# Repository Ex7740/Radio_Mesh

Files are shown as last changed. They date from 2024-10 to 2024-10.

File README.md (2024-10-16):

# Radio Mesh

A custom mesh network utilising 2.4GHz radio nodes using microcontrollers and nrf24l01

There are 3 types of node:

# Basic node: 
Simply just the microcontroller and nrf24l01 modules 

# Sensor node: 
More complex, Houses the microcontroller and nrf24l01, plus a varity of sensors, dependant on the application

# Storage node: 
Houses a Flash chip to hold sensor data and other data

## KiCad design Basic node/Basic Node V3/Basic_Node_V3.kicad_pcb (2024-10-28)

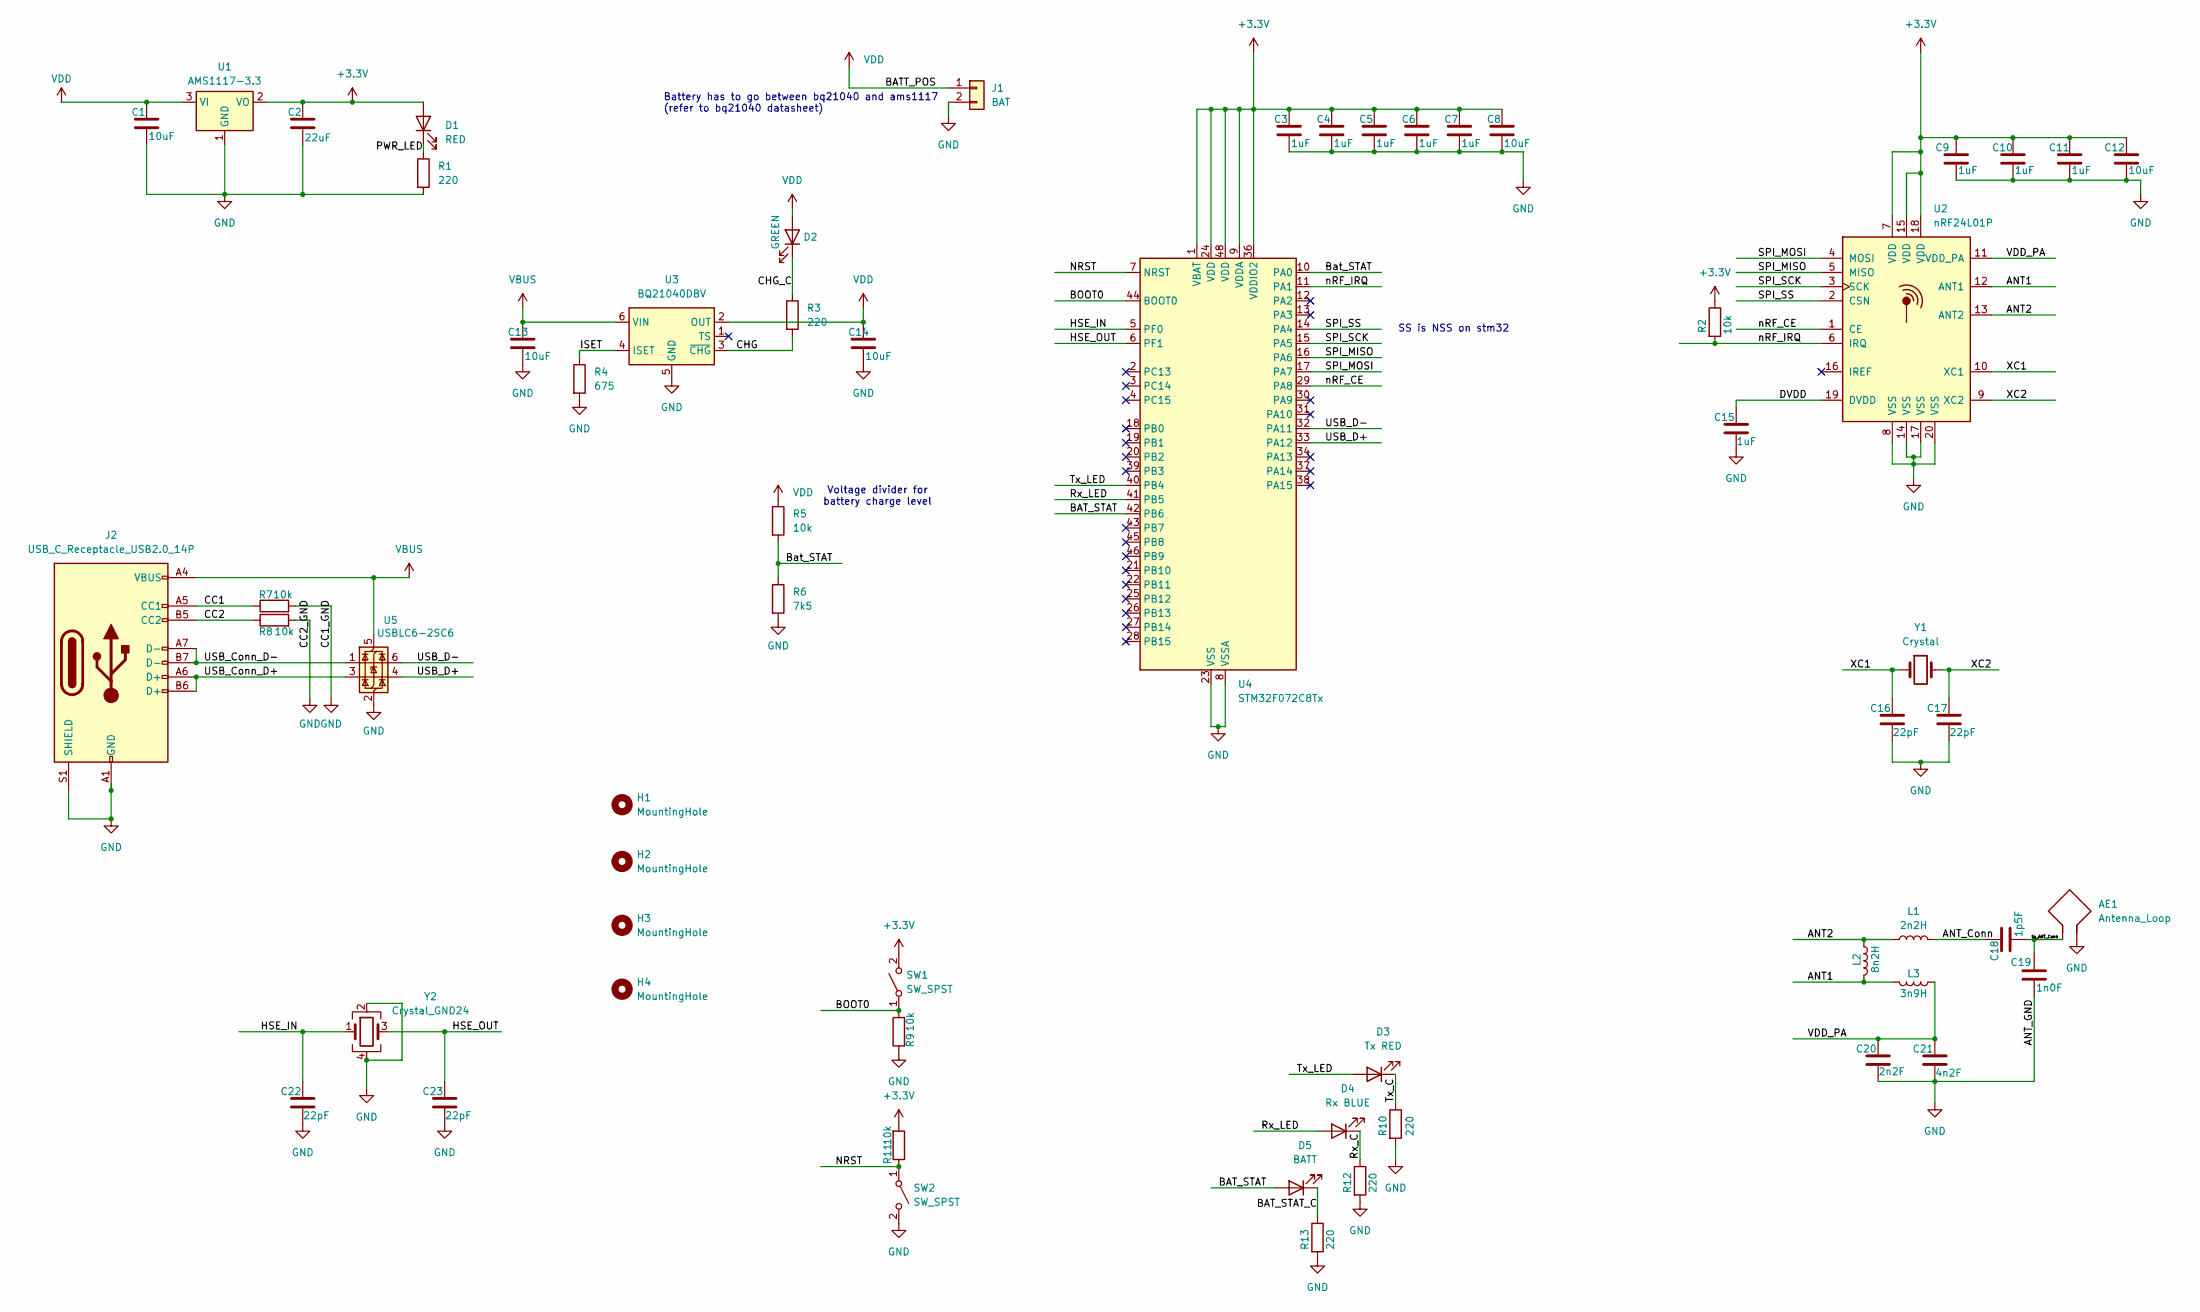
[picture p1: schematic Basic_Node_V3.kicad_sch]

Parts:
AE1: Antenna_Loop; Texas_SWRA117D_2.4GHz_Left
C1, C14: 10uF; C_0402_1005Metric
C2: 22uF; C_0402_1005Metric
C3, C4, C5, C6, C7, C9, C10, C11, C15: 1uF; C_0402_1005Metric
C8, C12, C13: 10uF; C_0603_1608Metric
C16, C17, C22, C23: 22pF; C_0402_1005Metric
C18: 1p5F; C_0402_1005Metric
C19: 1n0F; C_0402_1005Metric
C20: 2n2F; C_0402_1005Metric
C21: 4n2F; C_0402_1005Metric
D1: RED; LED_0603_1608Metric
D2: GREEN; LED_0603_1608Metric
D3: Tx RED; LED_0805_2012Metric
D4: Rx BLUE; LED_0805_2012Metric
D5: BATT; LED_0805_2012Metric
H1, H2, H3, H4: MountingHole; MountingHole_2.2mm_M2
J1: BAT; JST_PH_S2B-PH-K_1x02_P2.00mm_Horizontal
J2: USB_C_Receptacle_USB2.0_14P; USB_C_Receptacle_HRO_TYPE-C-31-M-12
L1: 2n2H; L_0603_1608Metric
L2: 8n2H; L_0603_1608Metric
L3: 3n9H; L_0603_1608Metric
R1, R3, R10, R12, R13: 220; R_0603_1608Metric
R2, R5, R8, R9, R11: 10k; R_0603_1608Metric
R4: 675; R_0603_1608Metric
R6: 7k5; R_0603_1608Metric
R7: 10k; L_0603_1608Metric
SW1, SW2: SW_SPST; SW_PUSH_6mm
U1: AMS1117-3.3; SOT-223-3_TabPin2
U2: nRF24L01P; QFN-20-1EP_4x4mm_P0.5mm_EP2.5x2.5mm
U3: BQ21040DBV; SOT-23-6
U4: STM32F072C8Tx; LQFP-48_7x7mm_P0.5mm
U5: USBLC6-2SC6; SOT-23-6
Y1: Crystal; Crystal_SMD_0603-2Pin_6.0x3.5mm
Y2: Crystal_GND24; Crystal_SMD_0603-4Pin_6.0x3.5mm

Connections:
+3.3V: C2.1, C3.1, C4.1, C5.1, C6.1, C7.1, C8.1, C9.1, C10.1, C11.1, C12.1, D1.2 (A), R2.1, R11.2, SW1.2 (B), U1.2 (VO), U2.7 (VDD), U2.15 (VDD), U2.18 (VDD), U4.1 (VBAT), U4.9 (VDDA), U4.24 (VDD), U4.36 (VDDIO2), U4.48 (VDD)
/ANT1: L2.2, L3.2, U2.12 (ANT1)
/ANT2: L1.1, L2.1, U2.13 (ANT2)
/ANT_Conn: C18.1, L1.2
/BAT_STAT: D5.2 (A), U4.42 (PB6)
/BAT_STAT_C: D5.1 (K), R13.1
/BOOT0: R9.2, SW1.1 (A), U4.44 (BOOT0)
/Bat_STAT: R5.2, R6.1, U4.10 (PA0)
/CC1: J2.A5 (CC1), R7.1
/CC2: J2.B5 (CC2), R8.1
/CHG: R3.2, U3.3 (~CHG)
/CHG_C: D2.1 (K), R3.1
/DVDD: C15.1, U2.19 (DVDD)
/HSE_IN: C22.1, U4.5 (PF0), Y2.1
/HSE_OUT: C23.1, U4.6 (PF1), Y2.3
/ISET: R4.1, U3.4 (ISET)
/NRST: R11.1, SW2.1 (A), U4.7 (NRST)
/PWR_LED: D1.1 (K), R1.1
/Rx_C: D4.1 (K), R12.1
/Rx_LED: D4.2 (A), U4.41 (PB5)
/SPI_MISO: U2.5 (MISO), U4.16 (PA6)
/SPI_MOSI: U2.4 (MOSI), U4.17 (PA7)
/SPI_SCK: U2.3 (SCK), U4.15 (PA5)
/SPI_SS: U2.2 (CSN), U4.14 (PA4)
/Tx_C: D3.1 (K), R10.1
/Tx_LED: D3.2 (A), U4.40 (PB4)
/USB_Conn_D+: J2.A6 (D+), J2.B6 (D+), U5.3 (I/O2)
/USB_Conn_D-: J2.A7 (D-), J2.B7 (D-), U5.1 (I/O1)
/USB_D+: U4.33 (PA12), U5.4 (I/O2)
/USB_D-: U4.32 (PA11), U5.6 (I/O1)
/VDD_PA: C20.1, C21.1, L3.1, U2.11 (VDD_PA)
/XC1: C16.1, U2.10 (XC1), Y1.1
/XC2: C17.1, U2.9 (XC2), Y1.2
/nRF_CE: U2.1 (CE), U4.29 (PA8)
/nRF_IRQ: R2.2, U2.6 (IRQ), U4.11 (PA1)
/to_ANT_Conn: AE1.1, C18.2, C19.1
GND: AE1.2, C1.2, C2.2, C3.2, C4.2, C5.2, C6.2, C7.2, C8.2, C9.2, C10.2, C11.2, C12.2, C13.2, C14.2, C15.2, C16.2, C17.2, C19.2, C20.2, C21.2, C22.2, C23.2, J1.2, J2.A1 (GND), J2.A12 (GND), J2.B1 (GND), J2.B12 (GND), J2.S1 (SHIELD), R1.2, R4.2, R6.2, R7.2, R8.2, R9.1, R10.2, R12.2, R13.2, SW2.2 (B), U1.1 (GND), U2.8 (VSS), U2.14 (VSS), U2.17 (VSS), U2.20 (VSS), U3.5 (GND), U4.8 (VSSA), U4.23 (VSS), U4.35 (VSS), U4.47 (VSS), U5.2 (GND), Y2.2, Y2.4
VBUS: C13.1, J2.A4 (VBUS), J2.A9 (VBUS), J2.B4 (VBUS), J2.B9 (VBUS), U3.6 (VIN), U5.5 (VBUS)
VDD: C1.1, C14.1, D2.2 (A), J1.1, R5.1, U1.3 (VI), U3.2 (OUT)

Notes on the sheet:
Voltage divider for battery charge level
Battery has to go between bq21040 and ams1117 (refer to bq21040 datasheet)
SS is NSS on stm32

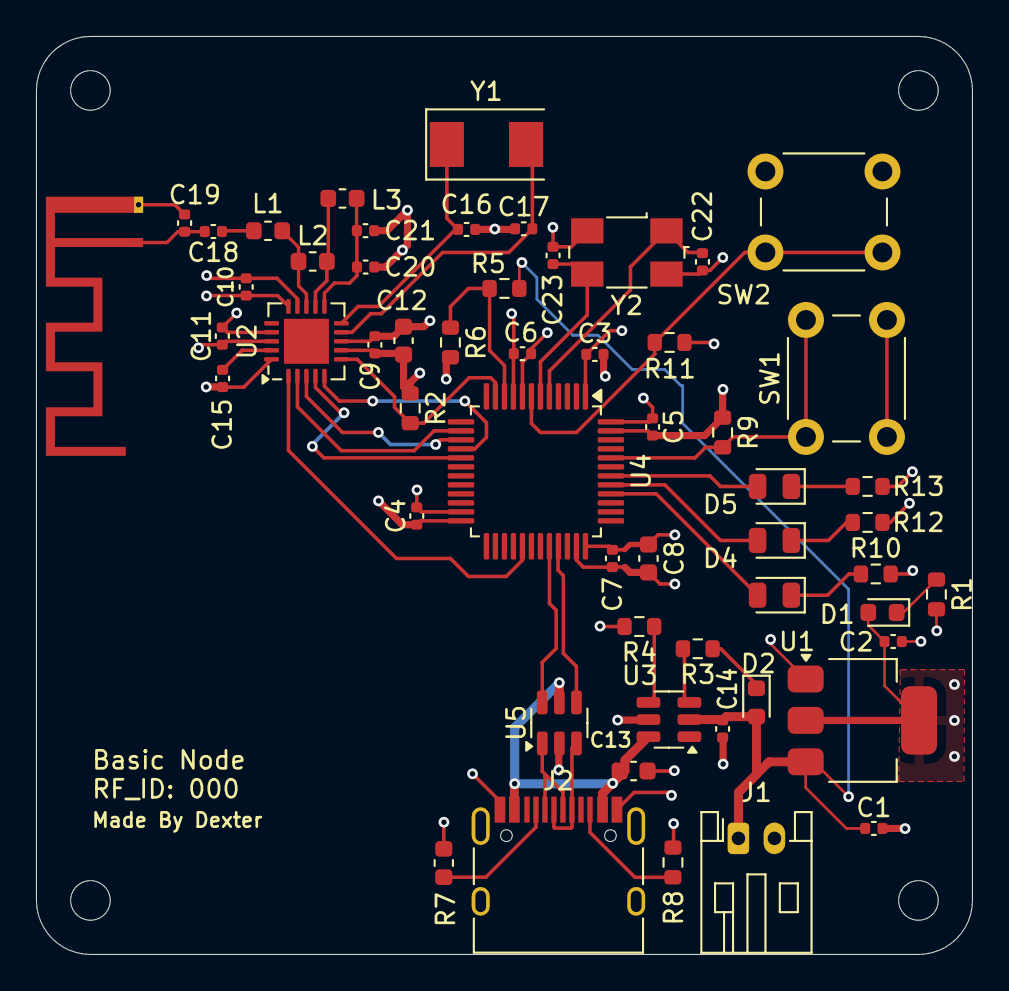
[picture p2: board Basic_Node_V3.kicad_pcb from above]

Board: 4 copper layers, 52.0 x 51.0 mm, 60 parts (0 on the bottom side), 39 nets.

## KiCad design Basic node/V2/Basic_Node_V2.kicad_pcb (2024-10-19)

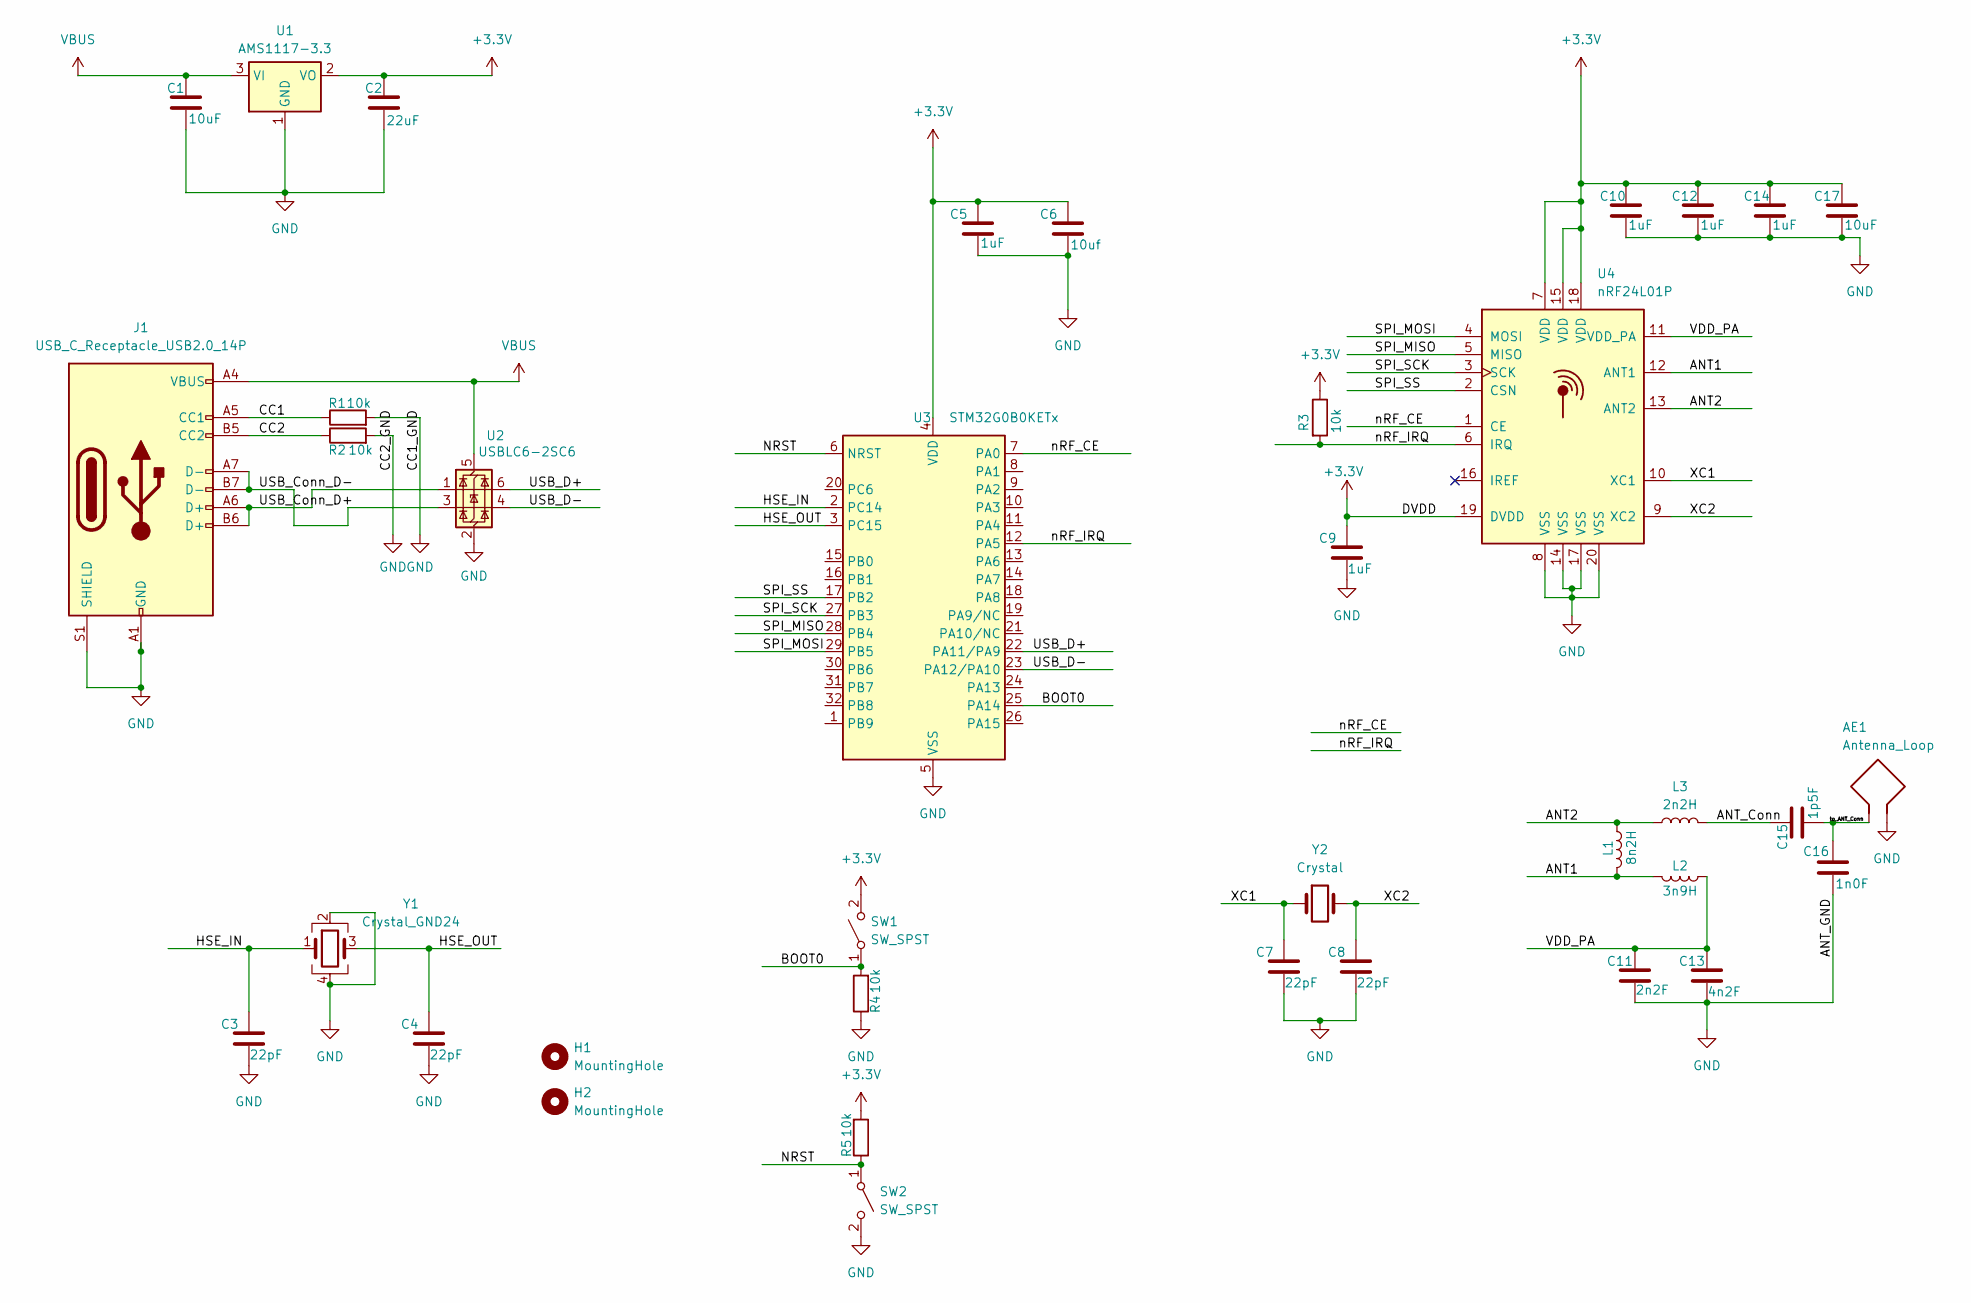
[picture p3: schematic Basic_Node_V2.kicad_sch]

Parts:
AE1: Antenna_Loop; Texas_SWRA117D_2.4GHz_Left
C1: 10uF; C_0402_1005Metric
C2: 22uF; C_0402_1005Metric
C3, C4, C7, C8: 22pF; C_0402_1005Metric
C5, C9, C10, C12, C14: 1uF; C_0402_1005Metric
C6: 10uf; C_0603_1608Metric
C11: 2n2F; C_0402_1005Metric
C13: 4n2F; C_0402_1005Metric
C15: 1p5F; C_0402_1005Metric
C16: 1n0F; C_0402_1005Metric
C17: 10uF; C_0603_1608Metric
H1, H2: MountingHole; MountingHole_2.2mm_M2
J1: USB_C_Receptacle_USB2.0_14P; USB_C_Receptacle_HRO_TYPE-C-31-M-12
L1: 8n2H; L_0603_1608Metric
L2: 3n9H; L_0603_1608Metric
L3: 2n2H; L_0603_1608Metric
R1: 10k; L_0603_1608Metric
R2, R3, R4, R5: 10k; R_0603_1608Metric
SW1, SW2: SW_SPST; SW_PUSH_6mm
U1: AMS1117-3.3; SOT-223-3_TabPin2
U2: USBLC6-2SC6; SOT-23-6
U3: STM32G0B0KETx; LQFP-32_7x7mm_P0.8mm
U4: nRF24L01P; QFN-20-1EP_4x4mm_P0.5mm_EP2.5x2.5mm
Y1: Crystal_GND24; Crystal_SMD_0603-4Pin_6.0x3.5mm
Y2: Crystal; Crystal_SMD_0603-2Pin_6.0x3.5mm

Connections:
+3.3V: C2.1, C5.1, C6.1, C9.1, C10.1, C12.1, C14.1, C17.1, R3.1, R5.2, SW1.2 (B), U1.2 (VO), U3.4 (VDD), U4.7 (VDD), U4.15 (VDD), U4.18 (VDD), U4.19 (DVDD)
/ANT1: L1.2, L2.2, U4.12 (ANT1)
/ANT2: L1.1, L3.1, U4.13 (ANT2)
/ANT_Conn: C15.1, L3.2
/BOOT0: R4.2, SW1.1 (A), U3.25 (PA14)
/CC1: J1.A5 (CC1), R1.1
/CC2: J1.B5 (CC2), R2.1
/HSE_IN: C3.1, U3.2 (PC14), Y1.1
/HSE_OUT: C4.1, U3.3 (PC15), Y1.3
/NRST: R5.1, SW2.1 (A), U3.6 (NRST)
/SPI_MISO: U3.28 (PB4), U4.5 (MISO)
/SPI_MOSI: U3.29 (PB5), U4.4 (MOSI)
/SPI_SCK: U3.27 (PB3), U4.3 (SCK)
/SPI_SS: U3.17 (PB2), U4.2 (CSN)
/USB_Conn_D+: J1.A6 (D+), J1.B6 (D+), U2.1 (I/O1)
/USB_Conn_D-: J1.A7 (D-), J1.B7 (D-), U2.3 (I/O2)
/USB_D+: U2.6 (I/O1), U3.22 (PA11/PA9)
/USB_D-: U2.4 (I/O2), U3.23 (PA12/PA10)
/VDD_PA: C11.1, C13.1, L2.1, U4.11 (VDD_PA)
/XC1: C7.1, U4.10 (XC1), Y2.1
/XC2: C8.1, U4.9 (XC2), Y2.2
/nRF_CE: U3.7 (PA0), U4.1 (CE)
/nRF_IRQ: R3.2, U3.12 (PA5), U4.6 (IRQ)
/to_ANT_Conn: AE1.1, C15.2, C16.1
GND: AE1.2, C1.2, C2.2, C3.2, C4.2, C5.2, C6.2, C7.2, C8.2, C9.2, C10.2, C11.2, C12.2, C13.2, C14.2, C16.2, C17.2, J1.A1 (GND), J1.A12 (GND), J1.B1 (GND), J1.B12 (GND), J1.S1 (SHIELD), R1.2, R2.2, R4.1, SW2.2 (B), U1.1 (GND), U2.2 (GND), U3.5 (VSS), U4.8 (VSS), U4.14 (VSS), U4.17 (VSS), U4.20 (VSS), Y1.2, Y1.4
VBUS: C1.1, J1.A4 (VBUS), J1.A9 (VBUS), J1.B4 (VBUS), J1.B9 (VBUS), U1.3 (VI), U2.5 (VBUS)

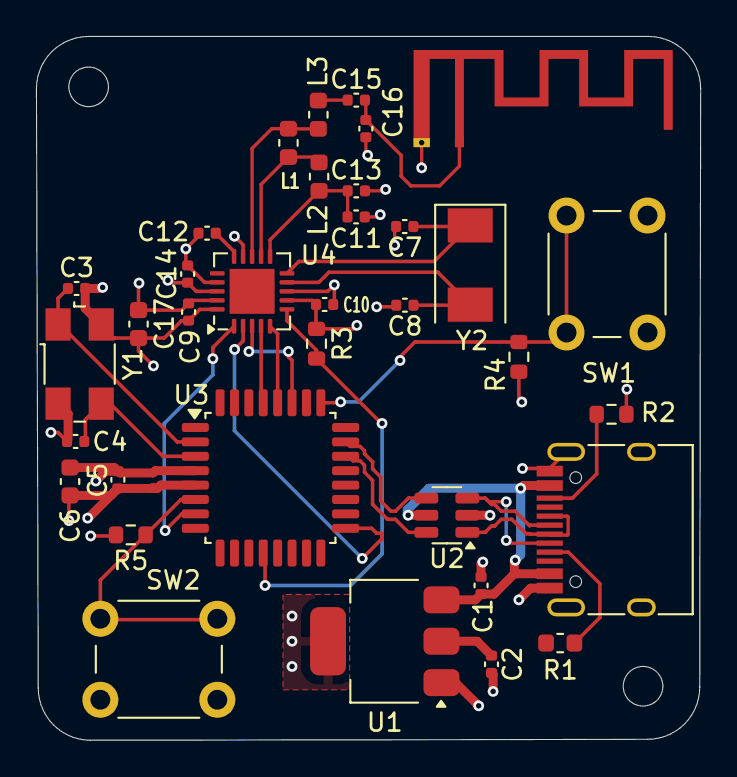
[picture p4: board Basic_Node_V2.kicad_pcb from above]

Board: 4 copper layers, 36.9 x 39.1 mm, 37 parts (0 on the bottom side), 26 nets.

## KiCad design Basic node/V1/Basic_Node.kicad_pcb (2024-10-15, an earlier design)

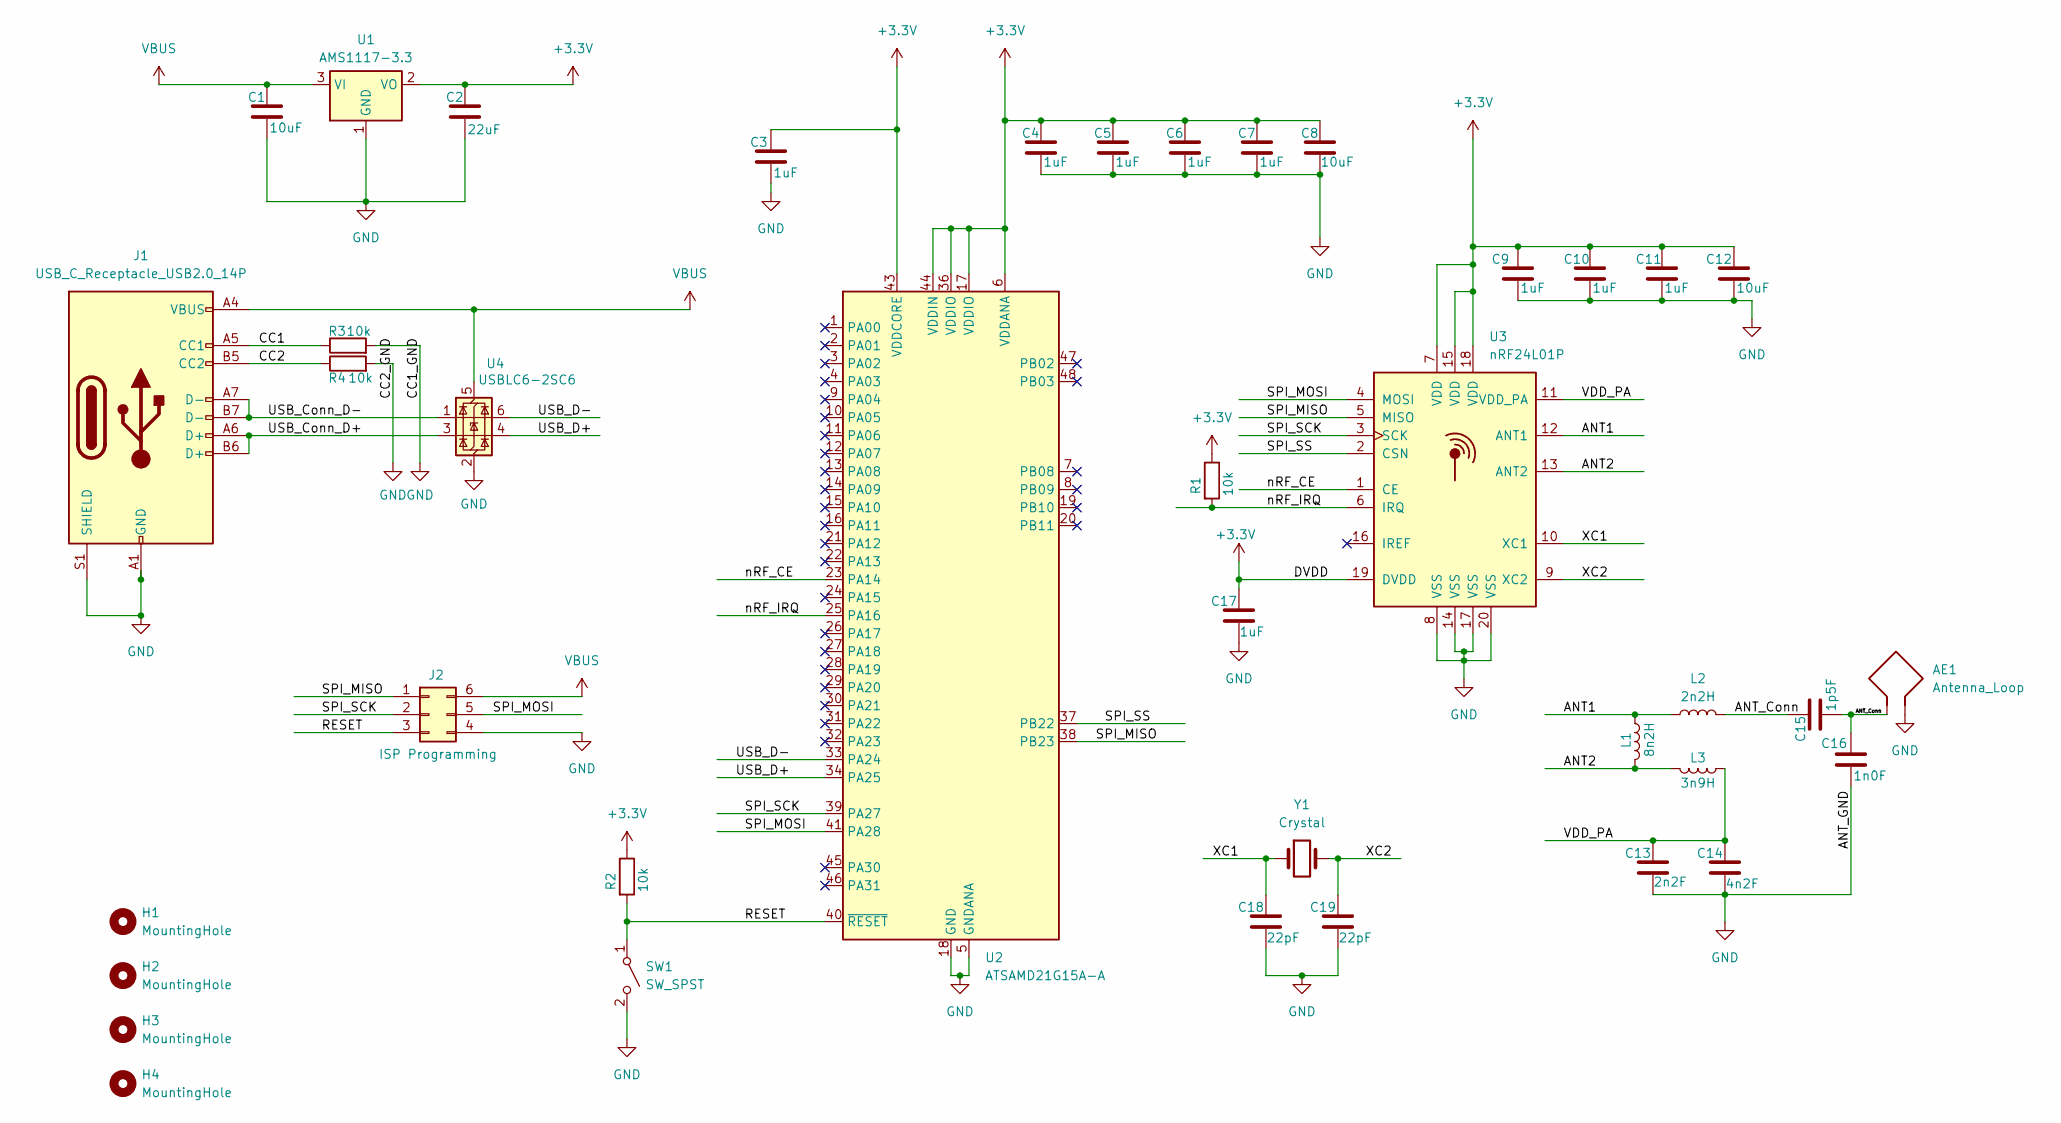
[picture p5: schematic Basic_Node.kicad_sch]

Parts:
AE1: Antenna_Loop; Texas_SWRA117D_2.4GHz_Left
C1, C8, C12: 10uF; C_0402_1005Metric
C2: 22uF; C_0402_1005Metric
C3, C4, C5, C6, C7, C9, C10, C11, C17: 1uF; C_0402_1005Metric
C13: 2n2F; C_0402_1005Metric
C14: 4n2F; C_0402_1005Metric
C15: 1p5F; C_0402_1005Metric
C16: 1n0F; C_0402_1005Metric
C18, C19: 22pF; C_0402_1005Metric
H1, H2, H3, H4: MountingHole; MountingHole_2.2mm_M2
J1: USB_C_Receptacle_USB2.0_14P; USB_C_Receptacle_HRO_TYPE-C-31-M-12
J2: ISP Programming; PinHeader_2x03_P2.54mm_Vertical
L1: 8n2H; L_0402_1005Metric
L2: 2n2H; L_0402_1005Metric
L3: 3n9H; L_0402_1005Metric
R1, R2, R3, R4: 10k; R_0402_1005Metric
SW1: SW_SPST; SW_SPST_PTS647_Sx38
U1: AMS1117-3.3; SOT-223-3_TabPin2
U2: ATSAMD21G15A-A; TQFP-48_7x7mm_P0.5mm
U3: nRF24L01P; QFN-20-1EP_4x4mm_P0.5mm_EP2.5x2.5mm
U4: USBLC6-2SC6; SOT-23-6
Y1: Crystal; Crystal_SMD_0603-2Pin_6.0x3.5mm

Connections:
+3.3V: C2.1, C3.1, C4.1, C5.2, C6.1, C7.1, C8.1, C9.1, C10.1, C11.1, C12.1, C17.1, R1.1, R2.1, U1.2 (VO), U2.6 (VDDANA), U2.17 (VDDIO), U2.36 (VDDIO), U2.43 (VDDCORE), U2.44 (VDDIN), U3.7 (VDD), U3.15 (VDD), U3.18 (VDD), U3.19 (DVDD)
/ANT1: L1.1, L2.1, U3.12 (ANT1)
/ANT2: L1.2, L3.2, U3.13 (ANT2)
/ANT_Conn: AE1.1, C15.1, C15.2, C16.1, L2.2
/CC1: J1.A5 (CC1), R3.1
/CC2: J1.B5 (CC2), R4.1
/RESET: J2.3, R2.2, SW1.1 (A), U2.40 (~RESET)
/SPI_MISO: J2.1, U2.38 (PB23), U3.5 (MISO)
/SPI_MOSI: J2.5, U2.41 (PA28), U3.4 (MOSI)
/SPI_SCK: J2.2, U2.39 (PA27), U3.3 (SCK)
/SPI_SS: U2.37 (PB22), U3.2 (CSN)
/USB_Conn_D+: J1.A6 (D+), J1.B6 (D+), U4.3 (I/O2)
/USB_Conn_D-: J1.A7 (D-), J1.B7 (D-), U4.1 (I/O1)
/USB_D+: U2.34 (PA25), U4.4 (I/O2)
/USB_D-: U2.33 (PA24), U4.6 (I/O1)
/VDD_PA: C13.1, C14.1, L3.1, U3.11 (VDD_PA)
/XC1: C18.1, U3.10 (XC1), Y1.1
/XC2: C19.1, U3.9 (XC2), Y1.2
/nRF_CE: U2.23 (PA14), U3.1 (CE)
/nRF_IRQ: R1.2, U2.25 (PA16), U3.6 (IRQ)
GND: AE1.2, C1.2, C2.2, C3.2, C4.2, C5.1, C6.2, C7.2, C8.2, C9.2, C10.2, C11.2, C12.2, C13.2, C14.2, C16.2, C17.2, C18.2, C19.2, J1.A1 (GND), J1.A12 (GND), J1.B1 (GND), J1.B12 (GND), J1.S1 (SHIELD), J2.4, R3.2, R4.2, SW1.2 (B), U1.1 (GND), U2.5 (GNDANA), U2.18 (GND), U2.35 (GND), U2.42 (GND), U3.8 (VSS), U3.14 (VSS), U3.17 (VSS), U3.20 (VSS), U4.2 (GND)
VBUS: C1.1, J1.A4 (VBUS), J1.A9 (VBUS), J1.B4 (VBUS), J1.B9 (VBUS), J2.6, U1.3 (VI), U4.5 (VBUS)

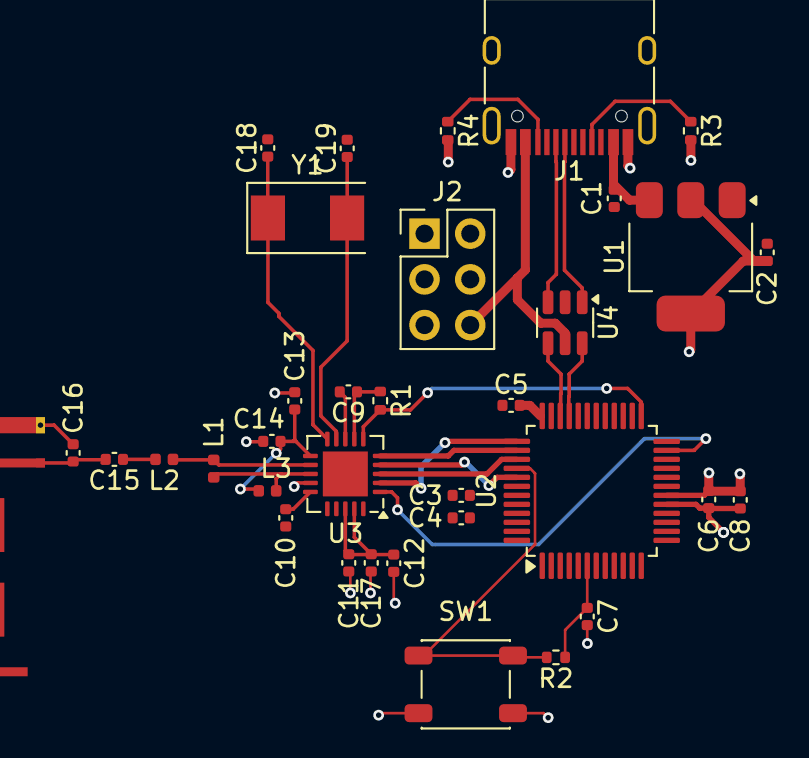
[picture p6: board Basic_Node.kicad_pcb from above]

Board: 4 copper layers, 39 parts (0 on the bottom side), 22 nets.

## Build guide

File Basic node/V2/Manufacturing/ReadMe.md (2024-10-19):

# The manufacturing files for basic node v2
